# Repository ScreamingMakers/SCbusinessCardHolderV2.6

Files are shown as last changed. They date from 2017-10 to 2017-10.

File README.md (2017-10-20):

# SCbusinessCardHolderV2.6
V2.6 of the Screaming Circuits open source, hackable, electronic business card holder 

The Screaming Circuits business card holder is a multi-function device intended for your amusement and as a demonstration of our workmanship.

It has 19 LEDs along the bottom of the board, with 16 being broken out to optional headers - for your hacking pleasure. Along the top, it uses the two user buttons, and the I2C/SPI and ICSP headrs to hold the business cards.

V2.6 also has all eight bits of ports A and C brought out to .1" headers. Port bits D5/An25, D6/TX, D7/RX, B0/A12, and B3/CCP2 are brought out to a separate header.

Note that this kit uses a pair of CR1220 coin cell batteries. The silk screen erronously calls for CR2032 batteries. Oops. My bad.
Mechanical build instructions:

After soldering in the I2C and ICSP pin headers, attaching the rubber feet, and inserting the batteries, it’s ready to go. Place it on your desk and put about ten business cards in. When someone takes a card (or if you pound on your keyboard hard enough) some of the LEDs will flash.

If you tip it up, so that the LEDs run along the bottom, it will act as a spirit level, and as a short ruler. It’s not angle calibrated. Doing so is up to you.

The microcontroller fitted is of the Microchip PIC18F46K22 family. This run of V2.6 was produced with a PIC18F46K22. V2.5 had uses CR2032 batteries and came with the PIC18F43K22 – the same MCU, but with less FLASH and SRAM. The accelerometer is a Freescale MMA8452Q. The schematic and layout were created with EagleCAD. The code was written and compiled with Microchip XC8 in Mplab-X.

One of the pin headers is connected to the I2C and SPI bus pins on the MCU. The other is connected to the Microchip ICSP (in circuit serial programming) pins on the MCU. Button Usr 1 is connected to I/O pin RB4, and Usr 2 is connected to RB5.

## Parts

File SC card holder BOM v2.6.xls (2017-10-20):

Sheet: BOM
Item # | Qty | Ref Des | Manufacturer | Manf part num | DigiKey Part number | Description | Package | Type | Side | Notes | Qty 1 | $ Ext | Qty 550 | Qty needed @550 | Ord Qty | $ Ext
1 | 1 | U1 | Microchip | PIC18F46K22-I/MV | PIC18F46K22-I/MV-ND | MCU | UQFN40 | BGA | Top |  | 2.29 | 2.29 | 1.9 | 550 | 600 | 1140.00
2 | 1 | U2 | Freescale | MMA8452QR1 | MMA8452QR1CT-ND | Accelerometer | QFN16 | BGA | Top |  | 1.43 | 1.43 | 1.02 | 550 | 600 | 612.00
3 | 10 | D1, D3, D5, D7, D9, D11, D13, D15, D17, D19 | Kingbright | APHHS1005SURCK | 754-1104-1-ND | LED red | 0402 | SMT | Top |  | 0.44 | 4.40 | 0.14928 | 5500 | 6000 | 895.68
4 | 9 | D2, D4, D6, D8, D10, D12, D14, D16, D18 | Kingbright | APG1005CGC-T | 754-1811-1-ND | LED green | 0402 | SMT | Top |  | 0.46 | 4.14 | 0.0936 | 4950 | 5500 | 514.80
5 | 5 | C1, C2, C3, C4, C5 | Taiyo | LMK105BJ104KV-F | 587-1227-1-ND | .1uf | 0402 | SMT | Top |  | 0.10 | 0.50 | 0.00325 | 2750 | 3000 | 9.75
6 | 1 | C6 | Samsung | CL05A475MQ5NRNC | 1276-1056-1-ND | 4.7uf | 0402 | SMT | Top |  | 0.21 | 0.21 | 0.0485 | 550 | 600 | 29.10
7 | 19 | R1-R19 | Stackpole | RMCF0402JT180R | RMCF0402JT180RCT-ND | 180 ohms | 0402 | SMT | Top |  | 0.10 | 1.90 | 0.00173 | 10450 | 12000 | 20.76
8 | 3 | R20, R21, R22 | Stackpole | RMCF0402JT10K0 | RMCF0402JT10K0CT-ND | 10K | 0402 | SMT | Top |  | 0.10 | 0.30 | 0.00328 | 1650 | 2000 | 6.56
9 | 1 | S1 | C&K Components | JS202011SCQN | 401-2002-1-ND | DPDT switch |  | SMT | Top |  | 0.46 | 0.46 | 0.3031 | 550 | 500 | 151.55
10 | 2 | S2, S3 | C&K Components | PTS645SK50SMTR92 LFS | CKN9087CT-ND | Momentary push |  | SMT | Top |  | 0.25 | 0.50 | 0.13125 | 1100 | 1200 | 157.50
11 | 2 | B1, B2 | MPD | BK-883 | BK-883-ND | 2032 holder |  | SMT | Bottom |  | 0.35 | 0.70 | 0.2448 | 1100 | 1200 | 293.76
12 | 2 | H1, H2 | Sullins | PREC006SFAN-RC | S1212EC-06-ND | 1x6 header ICSP |  | DNS | Top |  | 0.20 | 0.40 | 0.11586 | 1100 | 1200 | 139.03
13 | 4 | F1, F2, F3, F4 | 3M | SJ61A1 | SJ5746-0-ND | Rubber foot |  | DNS | Bottom |  | 0.10 | 0.39 | 0.0787 | 2200 | 2400 | 188.88
14 | 2 | Batt1, Batt2 | Energizer | CR2032VP | N189-ND | CR2032 battery |  | DNS | Bottom |  | 0.33 | 0.66 | 0.18411 | 1100 | 1200 | 220.93
 |  |  |  |  |  | PCB 3.5" x 1.65" |  |  |  |  |  | 0.00
 |  |  |  |  |  |  |  |  |  |  | Total parts, Qty 1 | 18.28 |  | Total parts, Qty 550 | 7.96 | 4380.30
 | Items 12, 13, and 14 need to be ordered and delivered to me, but not placed on the board |  |  |  |  |  |  | Assembly quote summary
 |  |  |  |  |  |  | BOM line items | 11
 | Note that item #13, the 3M feet only come in sheets of 144 |  |  |  |  |  | BGA | 2
 |  |  |  |  |  |  | SMT | 52
 |  |  |  |  |  |  | Thru-hole | 0
 |  |  |  |  |  |  | Total | 54

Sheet: LED
System V | 3
Diode drop | 0.385
 | 2.615
LED V | 1.95
C | 0.0036 | Max LED C | 0.0828
R V | 0.665
R Ohm | 184.7222222

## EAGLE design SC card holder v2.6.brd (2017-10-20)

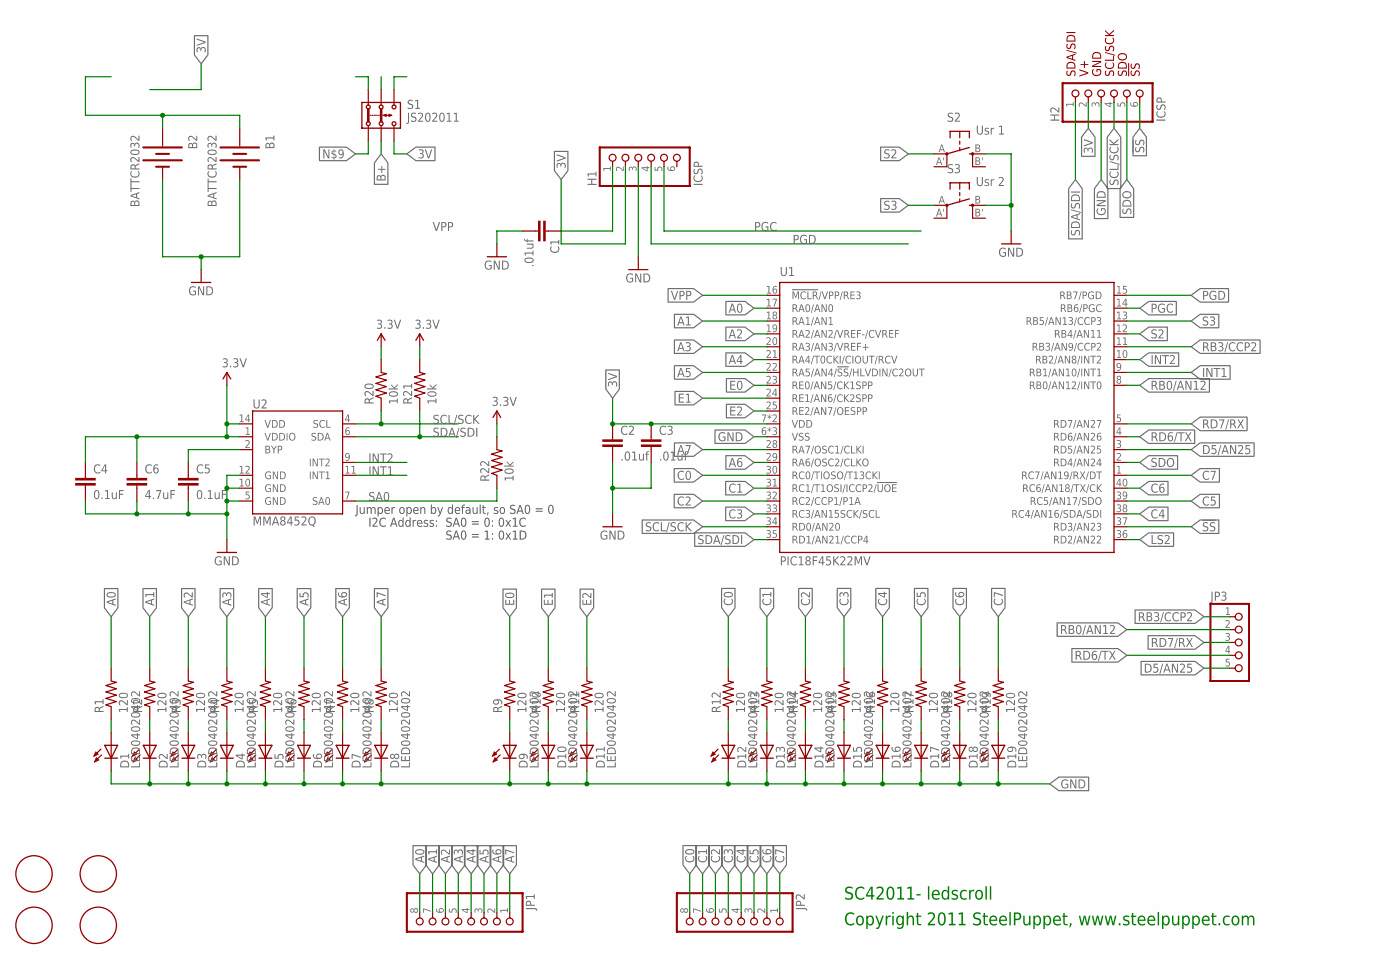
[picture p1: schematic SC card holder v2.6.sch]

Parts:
B1, B2: BATTCR2032; BATT_CR1220_SMT
C1, C2, C3: .01uf; 0402-CAP
C4, C5: 0.1uF; 0402-CAP
C6: 4.7uF; 0402-CAP
D1, D2, D3, D4, D5, D6, D7, D8, D9, D10, D11, D12, D13, D14, D15, D16, D17, D18, D19: LED04020402; LED0402
H1, H2: ICSP; 1X06-S
JP1, JP2: PINHD-1X08_2.54-S; 1X08-S
JP3: PINHD-1X05_2.54-S; 1X05-S
R1, R2, R3, R4, R5, R6, R7, R8, R9, R10, R11, R12, R13, R14, R15, R16, R17, R18, R19: 120; R0402
R20, R21, R22: 10k; 0402-RES
S1: JS202011; JS202011SMT
S2: Usr 1; EVQ-Q2
S3: Usr 2; EVQ-Q2
U1: PIC18F45K22MV; QFN40-5X5
U2: MMA8452Q; QFN-16_0.5MM
U$4, U$5, U$6, U$7: FID1.5

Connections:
3V: C2.1, C3.1, C4.1, C6.1, H1.2, H2.2, R20.2, R21.2, R22.2, S1.3 (3.2), S1.4 (3.1), U1.7 (VDD), U1.26 (VDD), U2.1 (VDDIO), U2.14 (VDD)
!SS: H2.6, U1.37 (RD3/AN23)
A0: JP1.8, R1.2, U1.17 (RA0/AN0)
A1: JP1.7, R2.2, U1.18 (RA1/AN1)
A2: JP1.6, R3.2, U1.19 (RA2/AN2/VREF-/CVREF)
A3: JP1.5, R4.2, U1.20 (RA3/AN3/VREF+)
A4: JP1.4, R5.2, U1.21 (RA4/T0CKI/CIOUT/RCV)
A5: JP1.3, R6.2, U1.22 (RA5/AN4/!SS!/HLVDIN/C2OUT)
A6: JP1.2, R7.2, U1.29 (RA6/OSC2/CLKO)
A7: JP1.1, R8.2, U1.28 (RA7/OSC1/CLKI)
B+: B1.1 (+), B1.3 (+), B2.1 (+), B2.3 (+), S1.2 (2.2), S1.5 (2.1)
BYP: C5.1, U2.2 (BYP)
C0: JP2.8, R12.2, U1.30 (RC0/TIOSO/T13CKI)
C1: JP2.7, R13.2, U1.31 (RC1/T1OSI/ICCP2/!UOE)
C2: JP2.6, R14.2, U1.32 (RC2/CCP1/P1A)
C3: JP2.5, R15.2, U1.33 (RC3/AN15SCK/SCL)
C4: JP2.4, R16.2, U1.38 (RC4/AN16/SDA/SDI)
C5: JP2.3, R17.2, U1.39 (RC5/AN17/SDO)
C6: JP2.2, R18.2, U1.40 (RC6/AN18/TX/CK)
C7: JP2.1, R19.2, U1.1 (RC7/AN19/RX/DT)
D5/AN25: JP3.5, U1.3 (RD5/AN25)
E0: R9.2, U1.23 (RE0/AN5/CK1SPP)
E1: R10.2, U1.24 (RE1/AN6/CK2SPP)
E2: R11.2, U1.25 (RE2/AN7/OESPP)
GND: B1.2 (-), B2.2 (-), C1.2, C2.2, C3.2, C4.2, C5.2, C6.2, D1.C, D2.C, D3.C, D4.C, D5.C, D6.C, D7.C, D8.C, D9.C, D10.C, D11.C, D12.C, D13.C, D14.C, D15.C, D16.C, D17.C, D18.C, D19.C, H1.3, H2.3, S2.B (S), S3.B (S), U1.6 (VSS), U1.27 (VSS), U1.41 (VSS), U2.5 (GND), U2.10 (GND), U2.12 (GND)
INT1: U1.9 (RB1/AN10/INT1), U2.11 (INT1)
INT2: U1.10 (RB2/AN8/INT2), U2.9 (INT2)
LS2: U1.36 (RD2/AN22)
unnamed: D1.A, R1.1
unnamed: D2.A, R2.1
unnamed: D3.A, R3.1
unnamed: D4.A, R4.1
unnamed: D9.A, R9.1
unnamed: D10.A, R10.1
unnamed: D11.A, R11.1
unnamed: D13.A, R13.1
unnamed: D14.A, R14.1
unnamed: D15.A, R15.1
unnamed: D12.A, R12.1
unnamed: D6.A, R6.1
unnamed: D7.A, R7.1
unnamed: D16.A, R16.1
unnamed: D17.A, R17.1
unnamed: D8.A, R8.1
unnamed: D5.A, R5.1
unnamed: D18.A, R18.1
unnamed: D19.A, R19.1
PGC: H1.5, U1.14 (RB6/PGC)
PGD: H1.4, U1.15 (RB7/PGD)
RB0/AN12: JP3.2, U1.8 (RB0/AN12/INT0)
RB3/CCP2: JP3.1, U1.11 (RB3/AN9/CCP2)
RD6/TX: JP3.4, U1.4 (RD6/AN26)
RD7/RX: JP3.3, U1.5 (RD7/AN27)
S2: S2.A, U1.12 (RB4/AN11)
S3: S3.A, U1.13 (RB5/AN13/CCP3)
SA0: R22.1, U2.7 (SA0)
SCL/SCK: H2.4, R20.1, U1.34 (RD0/AN20), U2.4 (SCL)
SDA/SDI: H2.1, R21.1, U1.35 (RD1/AN21/CCP4), U2.6 (SDA)
SDO: H2.5, U1.2 (RD4/AN24)
VPP: C1.1, H1.1, U1.16 (!MCLR!/VPP/RE3)

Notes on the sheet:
SC42011- ledscroll
Copyright 2011 SteelPuppet, www.steelpuppet.com
SDA/SDI
GND
SCL/SCK
SDO
!SS
I2C Address:
SA0 = 0: 0x1C
SA0 = 1: 0x1D
Jumper open by default, so SA0 = 0

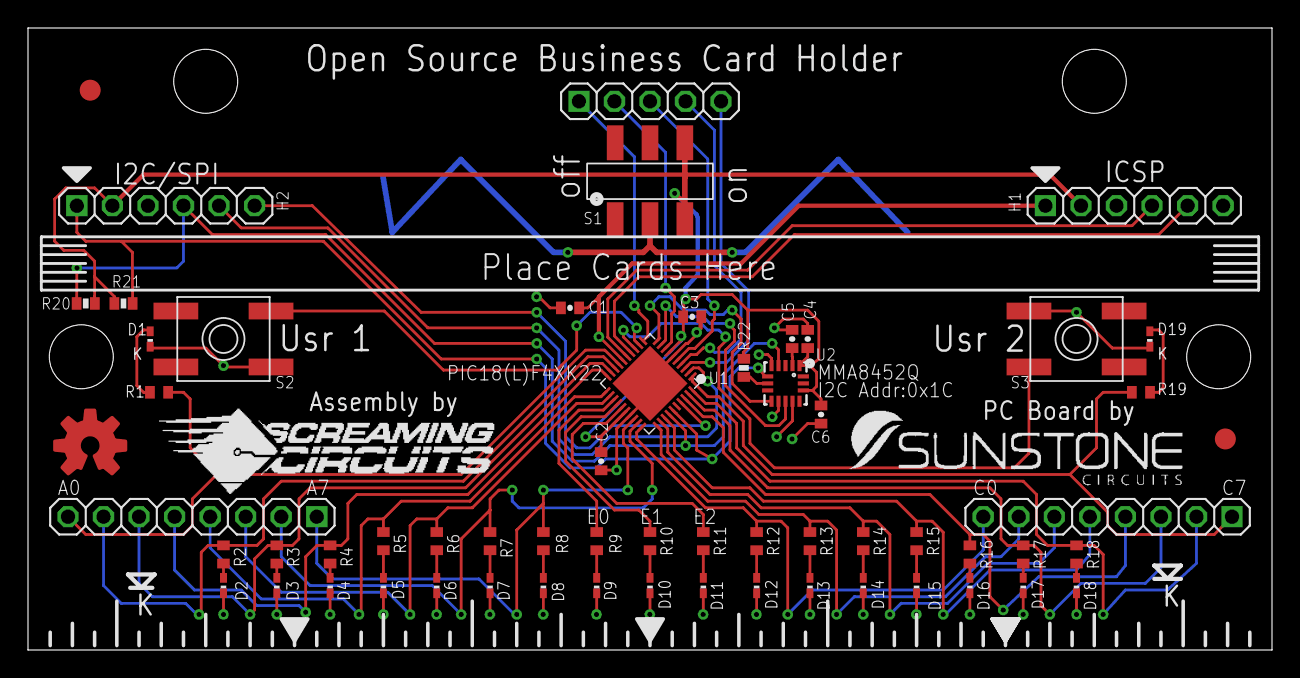
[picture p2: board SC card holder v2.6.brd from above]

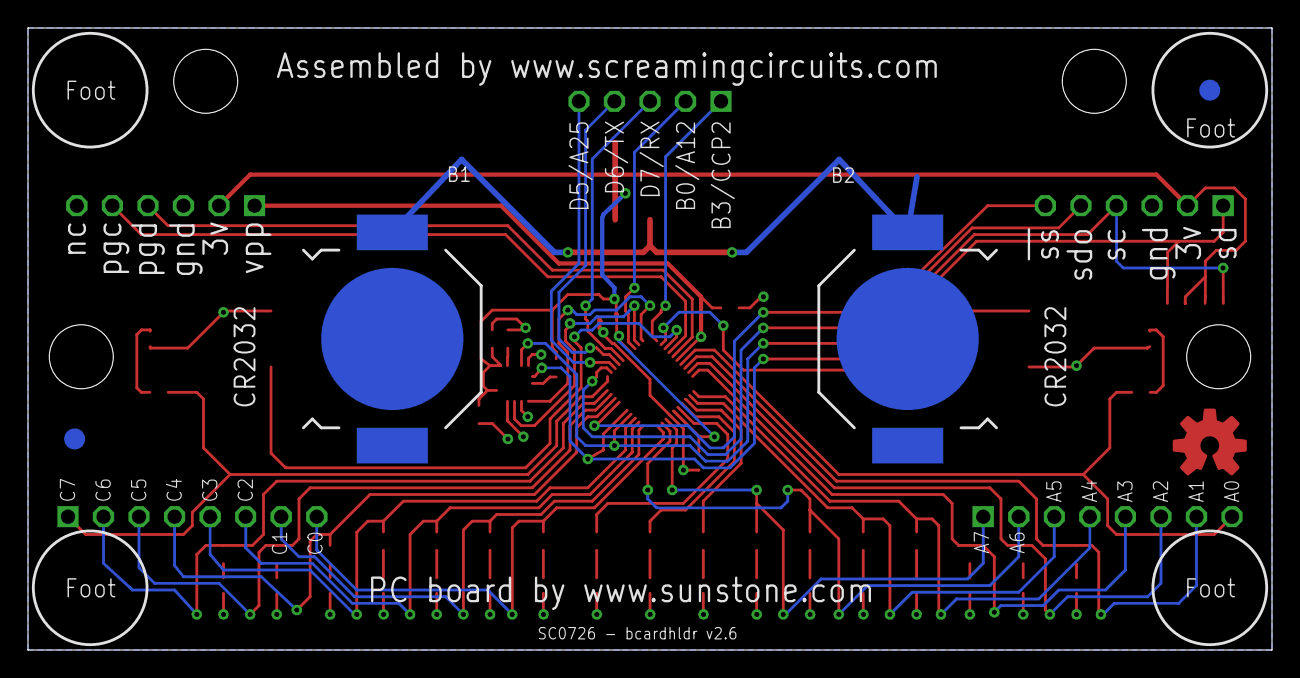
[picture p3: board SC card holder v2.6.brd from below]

Board: 2 copper layers, 88.9 x 44.5 mm, 66 parts (4 on the bottom side), 59 nets.

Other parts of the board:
U$1: SUNSTONE-LOGO
U$2: OSHWLOGO_TOP_0.2
U$3: SC-LOGO
